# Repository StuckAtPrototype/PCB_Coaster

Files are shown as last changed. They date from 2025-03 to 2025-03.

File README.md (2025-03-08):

# PCB Coaster - StuckAtPrototype

## Youtube Video
A bit of a back-story of how this project came to be. 

My Kickstarter failed, so I open sourced it (https://youtu.be/eh7vAip87YQ)

Sub if you like what you see.

*Some pictures of the project*

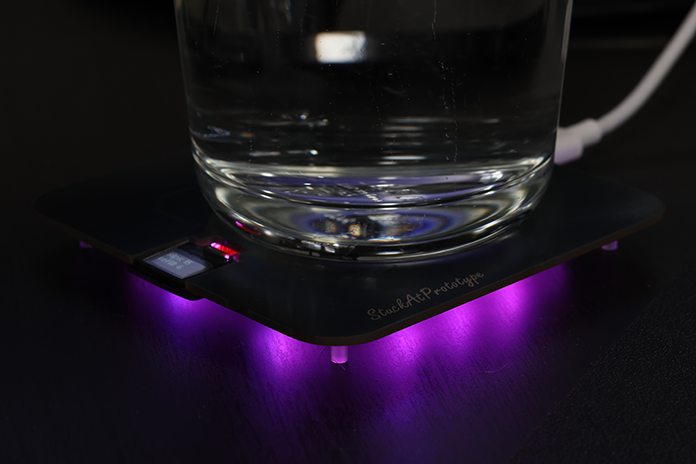
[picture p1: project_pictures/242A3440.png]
Picture of PCB car


## Project Structure
The project consists of
1. Firmware
2. Hardware
3. Mechanical

These are structured into their own files. I could have used submodules, but decided against it.  

### 1. Firmware
Code for the coaster. This lives on the ESP32

#### Requirements
- ESP32 IDF version 5.4
- Target set to ESP32-H2
- Install managed components  

##### Required Managed Components
1. lvgl 
2. espressif esp lvgl port

### 2. Hardware

#### Schematic
PDF schematic included for your viewing pleasure. File `PCB_Coaster_v0.2_Schematic.pdf`

#### PCBs
All the gerber files you'd need to send to a fab house. File `PCB coaster v0.2.zip`

#### BOM
Bill of materials file `coaster-BOM-v0.2.csv`

#### Kicad
All the files you'd need to expand and work on this further. If you'd like.

### 3. Mechanical

#### Diffuser
`PCB Coaster diffuser.step`
You can print this part with clear ABS fillament for best results. 

#### Screen Holder
`PCB Coaster screen holder.step`
I printed this part with an SLA printer, it can probably do ok with a filament printer too 

#### Spacers
`PCB Coaster spacer.step`
These print best on SLA. Filament printer will not achieve flat tops, though it might work. Best printed with SLA.  

#### Screen protector
I used a Cricut machine and a thin accental plastic to cut out the screen protector. Ideally, this would be made of tempered glass. (maybe one day)

## If you take it further
Let me know if you ever make one of these, I'd love to see it. Seriously, that'd be exciting and inspiring to keep making my projects open source!

## And if you got this far...
Consider signing up for my mailing list. As I run into problems when making these projects, I fire off an email with a small write up explaing the problem and the solution I found. Here is the link https://landing.stuckatprototype.com/exclusive

Stay fun, StuckAtPrototype

---
## License
### Apache 2.0 -- i.e. use as you'd like
http://www.apache.org/licenses/LICENSE-2.0

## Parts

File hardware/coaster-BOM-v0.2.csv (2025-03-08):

Id | Designator | Footprint | Quantity | Designation | Supplier and ref |  | PnP
1 | R17 | R_0603_1608Metric | 1 | 100k |  |  | y
2 | R5,R4 | R_0603_1608Metric | 2 | 5k1 |  |  | y
3 | U3 | AP2204 | 1 | AP2205 | AP2205-33W5-7 | 3v3
4 | U1 | AP2204 | 1 | AP2205 | AP2205-50W5-7 | 5v |  | bought
5 | C18,C4,C28,C10,C11,C17,C5,C3,C23,C6,C24,C8,C13,C7,C9,C21 | C_0603_1608Metric | 16 | 0.1uF |  |  | y
6 | LED9,LED6,LED1,LED8,LED7,LED3,LED11,LED4,LED5,LED10,LED2 | IN-PI15_INL | 11 | IN-PI15TAT5R5G5B | IN-PI15TAT5R5G5B |  |  | bought
7 | R11,R9,R10,R12 | R_0603_1608Metric | 4 | 1.43K |  |  | y
8 | R3 | R_0603_1608Metric | 1 | 470 |  |  |  | bought
9 | C25,C19,C1 | C_0603_1608Metric | 3 | 2.2uF |  |  |  | bought
10 | R14,R13,R1,R2,R16 | R_0603_1608Metric | 5 | 10k |  |  | y
11 | P1 | GCT_USB4105-GF-A | 1 | USB_C_Plug_USB2.0 | USB4125-GF-A |  |  | bought
12 | C12,C27 | C_0603_1608Metric | 2 | 4.7uF |  |  | y
13 | C26,C2 | C_0603_1608Metric | 2 | 10uF |  |  | y
14 | D1 | D_SOD-523 | 1 | TPD1E10B06DPYR | UCLAMP0501H.TCT | *Changed |  | bought
15 | Q1 | SOT-23 | 1 | BSS138 | BSS138 |  |  | bought
16 | R8,R18,R7 | R_0603_1608Metric | 3 | 10K |  |  | y
17 | P3,P2,P5,P4 | SEN0297 | 4 | SEN0297 | SEN0297
18 | U2 | MODULE_ESP32-H2-MINI-1-H2 | 1 | ESP32-H2-MINI-1 | ESP32-H2-MINI-1
19 | C14,C15,C20,C22 | C_0603_1608Metric | 2 | 1uF |  |  | y
20 | C16 | C_0603_1608Metric | 1 | 47uF
21 | R6 | R_0603_1608Metric | 1 | 1M |  |  | y
22 | S3 | TL1016AAF220QG | 1 | TL1016AAF220QG | TL1016AAF220QG |  |  | bought

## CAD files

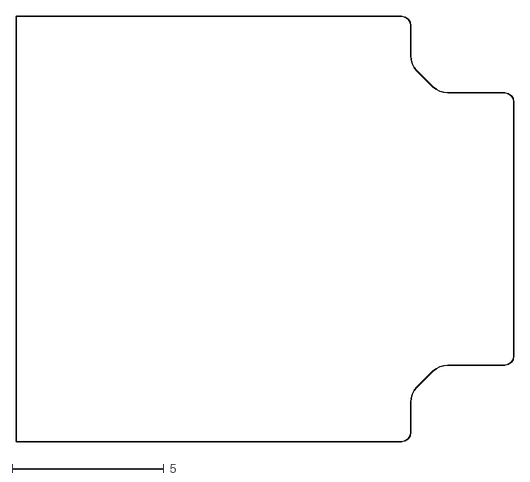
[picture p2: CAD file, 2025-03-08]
mechanical/screen-cover.dxf
16.4 x 14.0

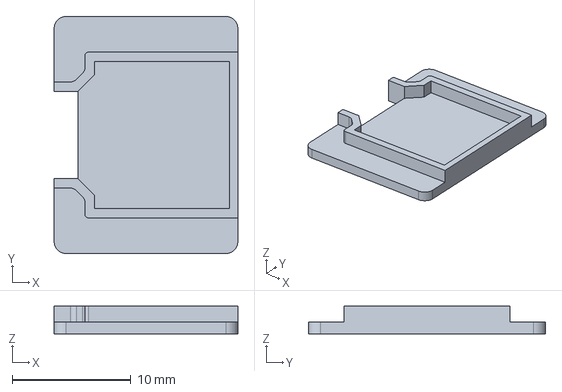
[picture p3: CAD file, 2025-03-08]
mechanical/PCB Coaster screen holder.step
15.5 x 20.0 x 2.36 mm

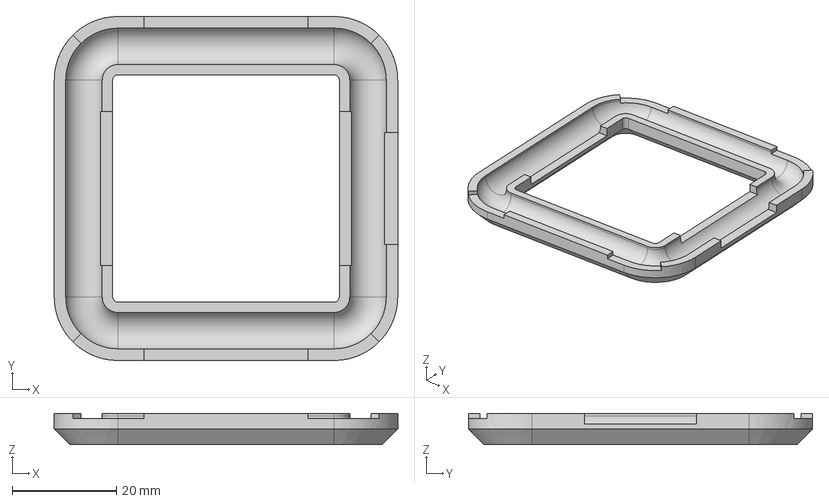
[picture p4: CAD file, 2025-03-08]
mechanical/PCB Coaster diffuser.step
65.8 x 65.9 x 6.00 mm

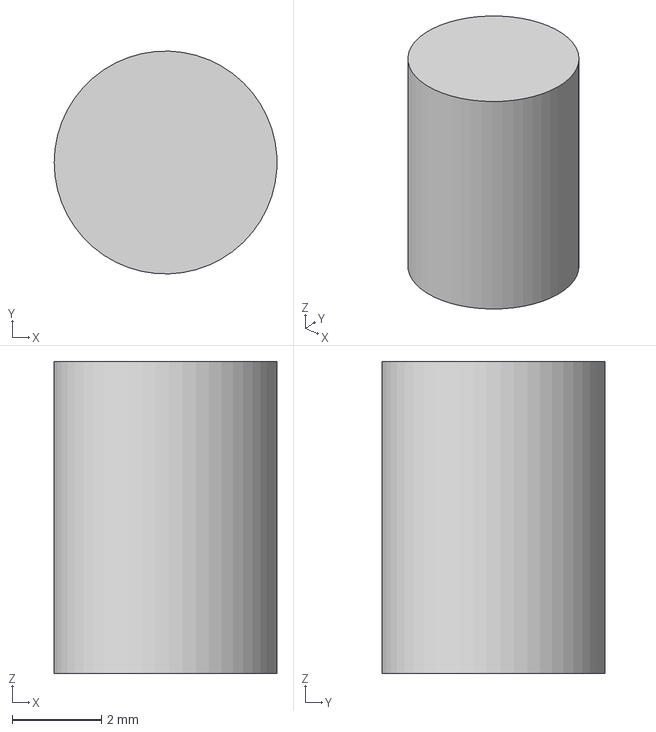
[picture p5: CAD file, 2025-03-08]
mechanical/PCB Coaster spacer.step
5.00 x 5.00 x 7.00 mm

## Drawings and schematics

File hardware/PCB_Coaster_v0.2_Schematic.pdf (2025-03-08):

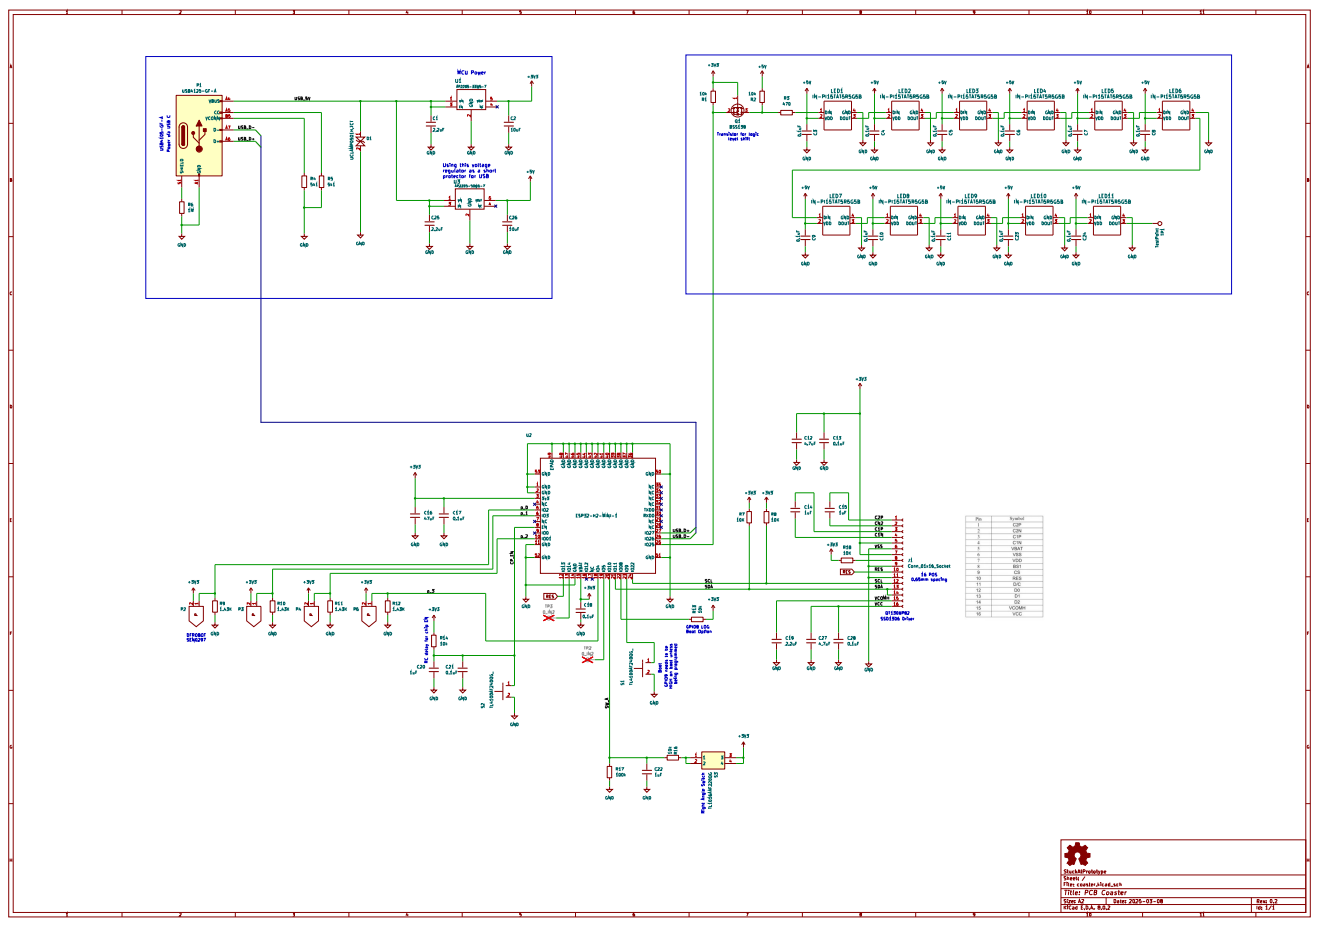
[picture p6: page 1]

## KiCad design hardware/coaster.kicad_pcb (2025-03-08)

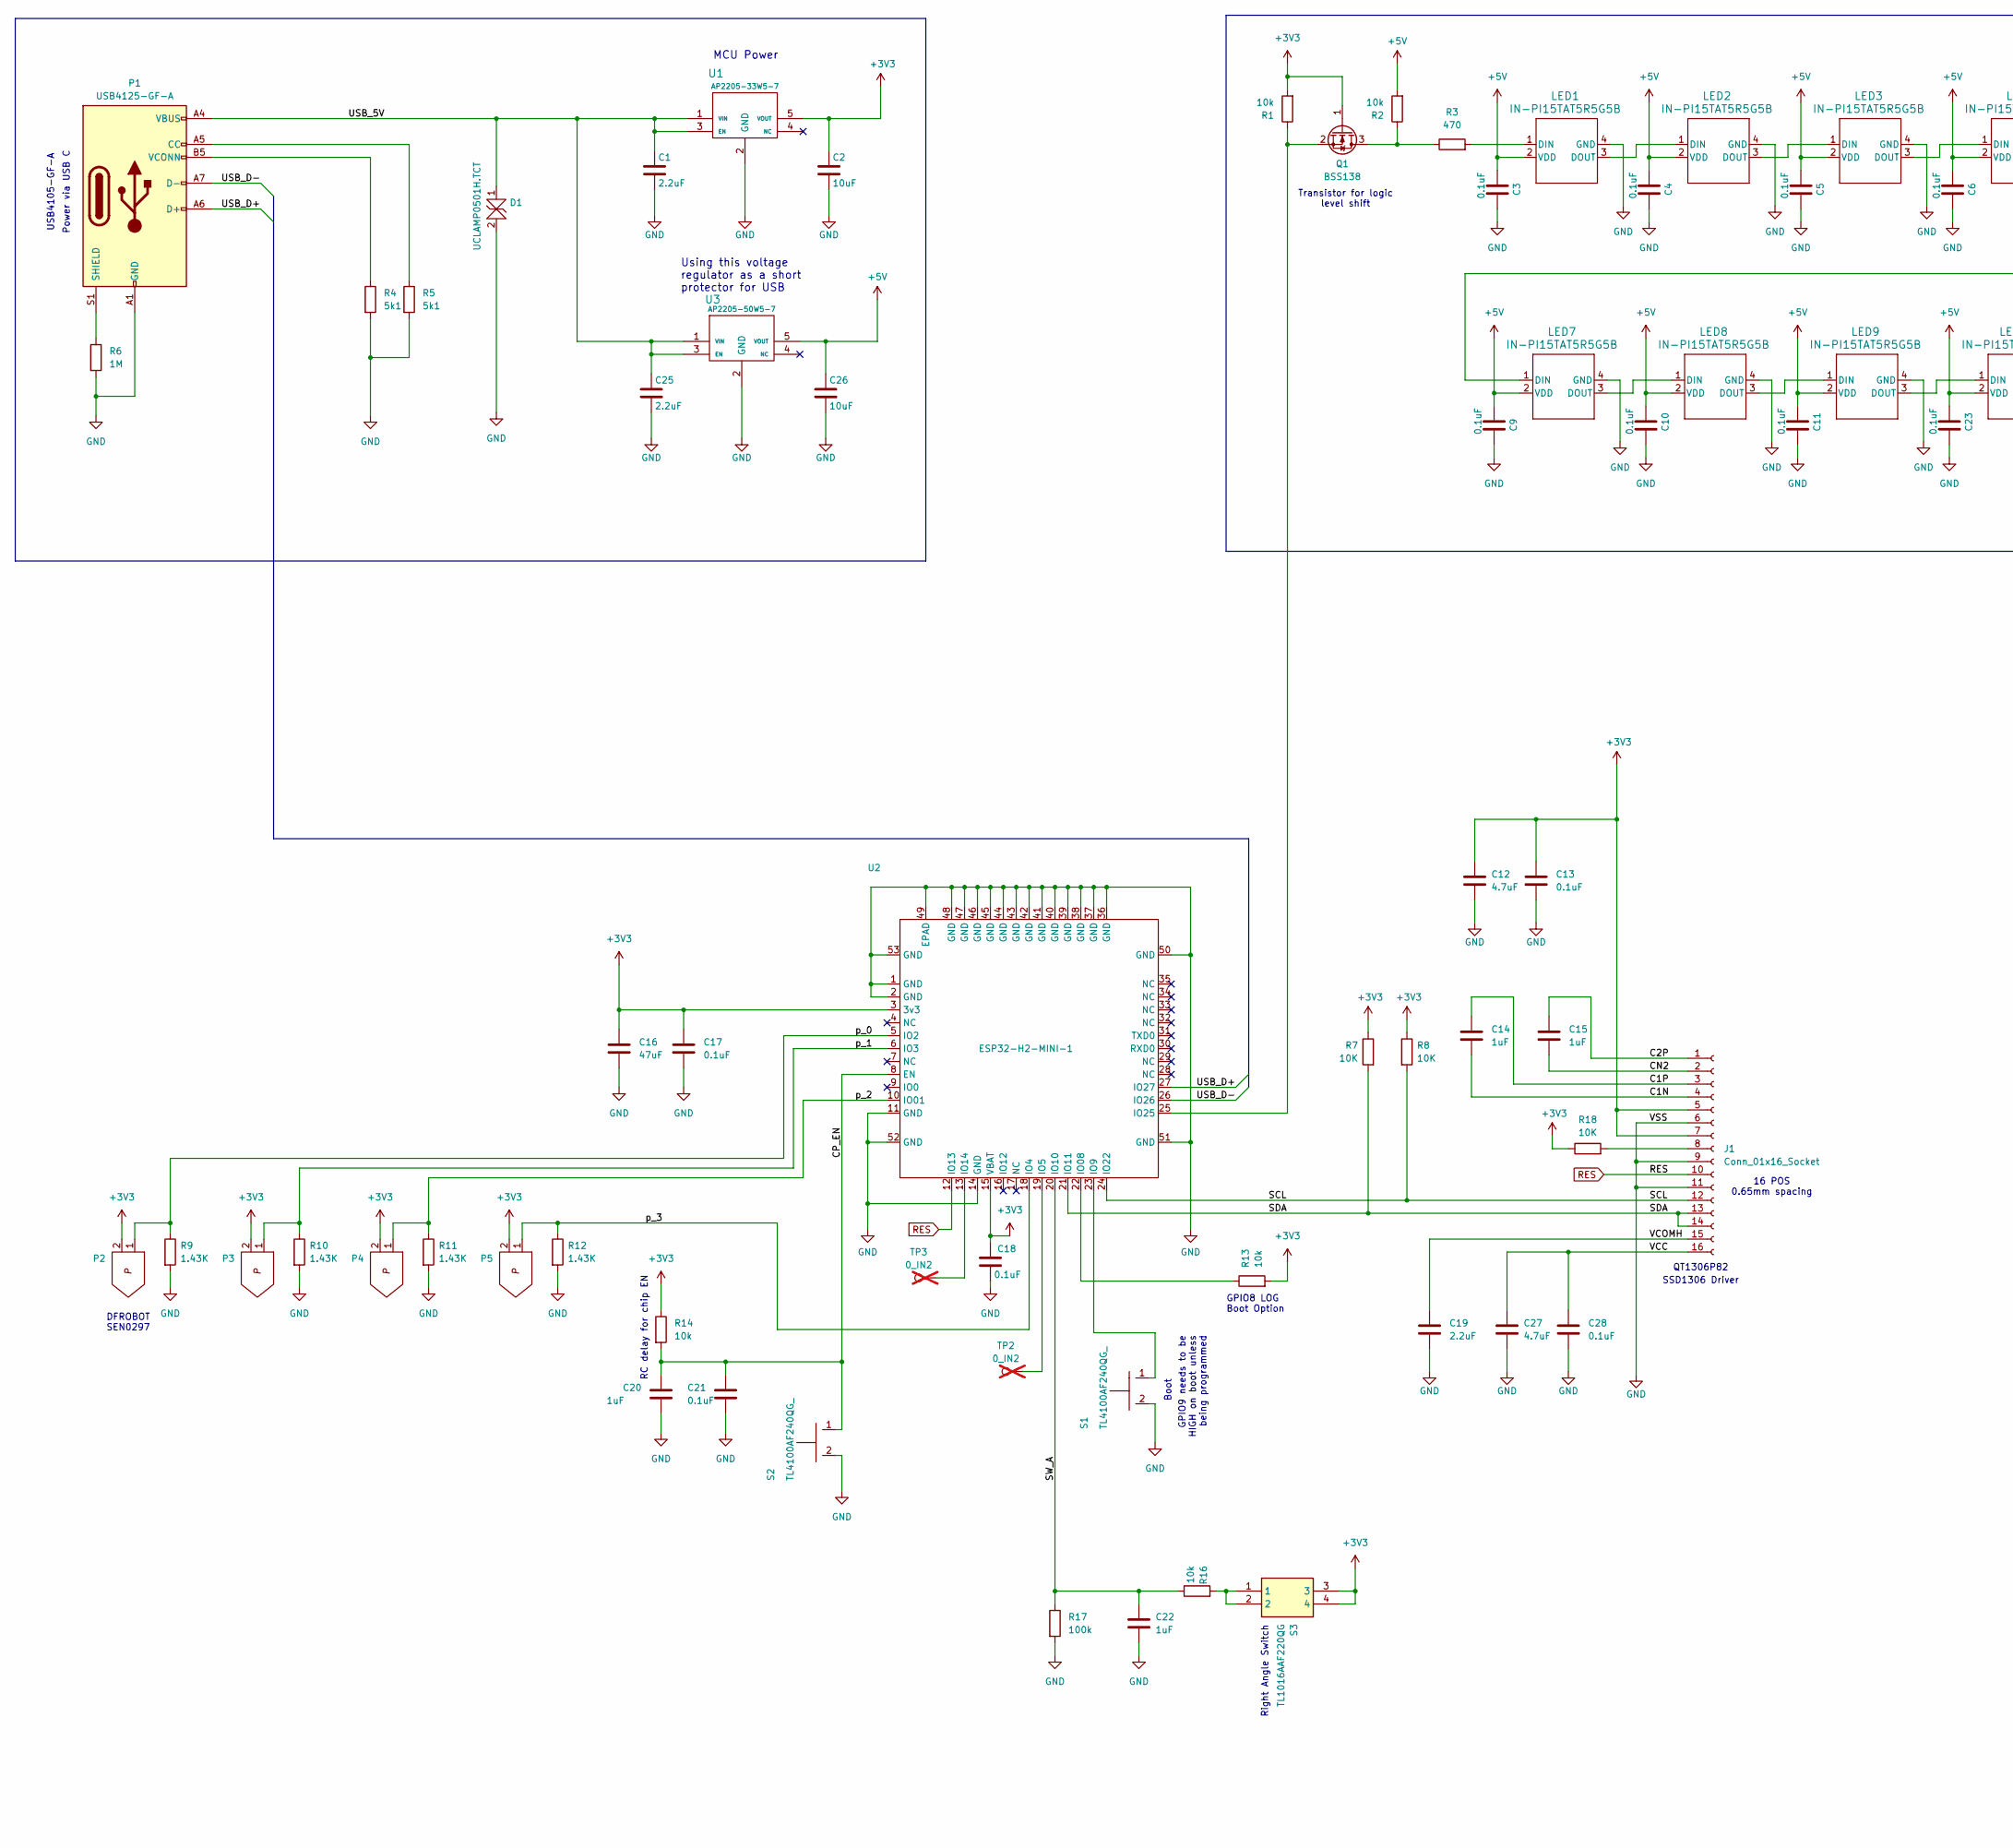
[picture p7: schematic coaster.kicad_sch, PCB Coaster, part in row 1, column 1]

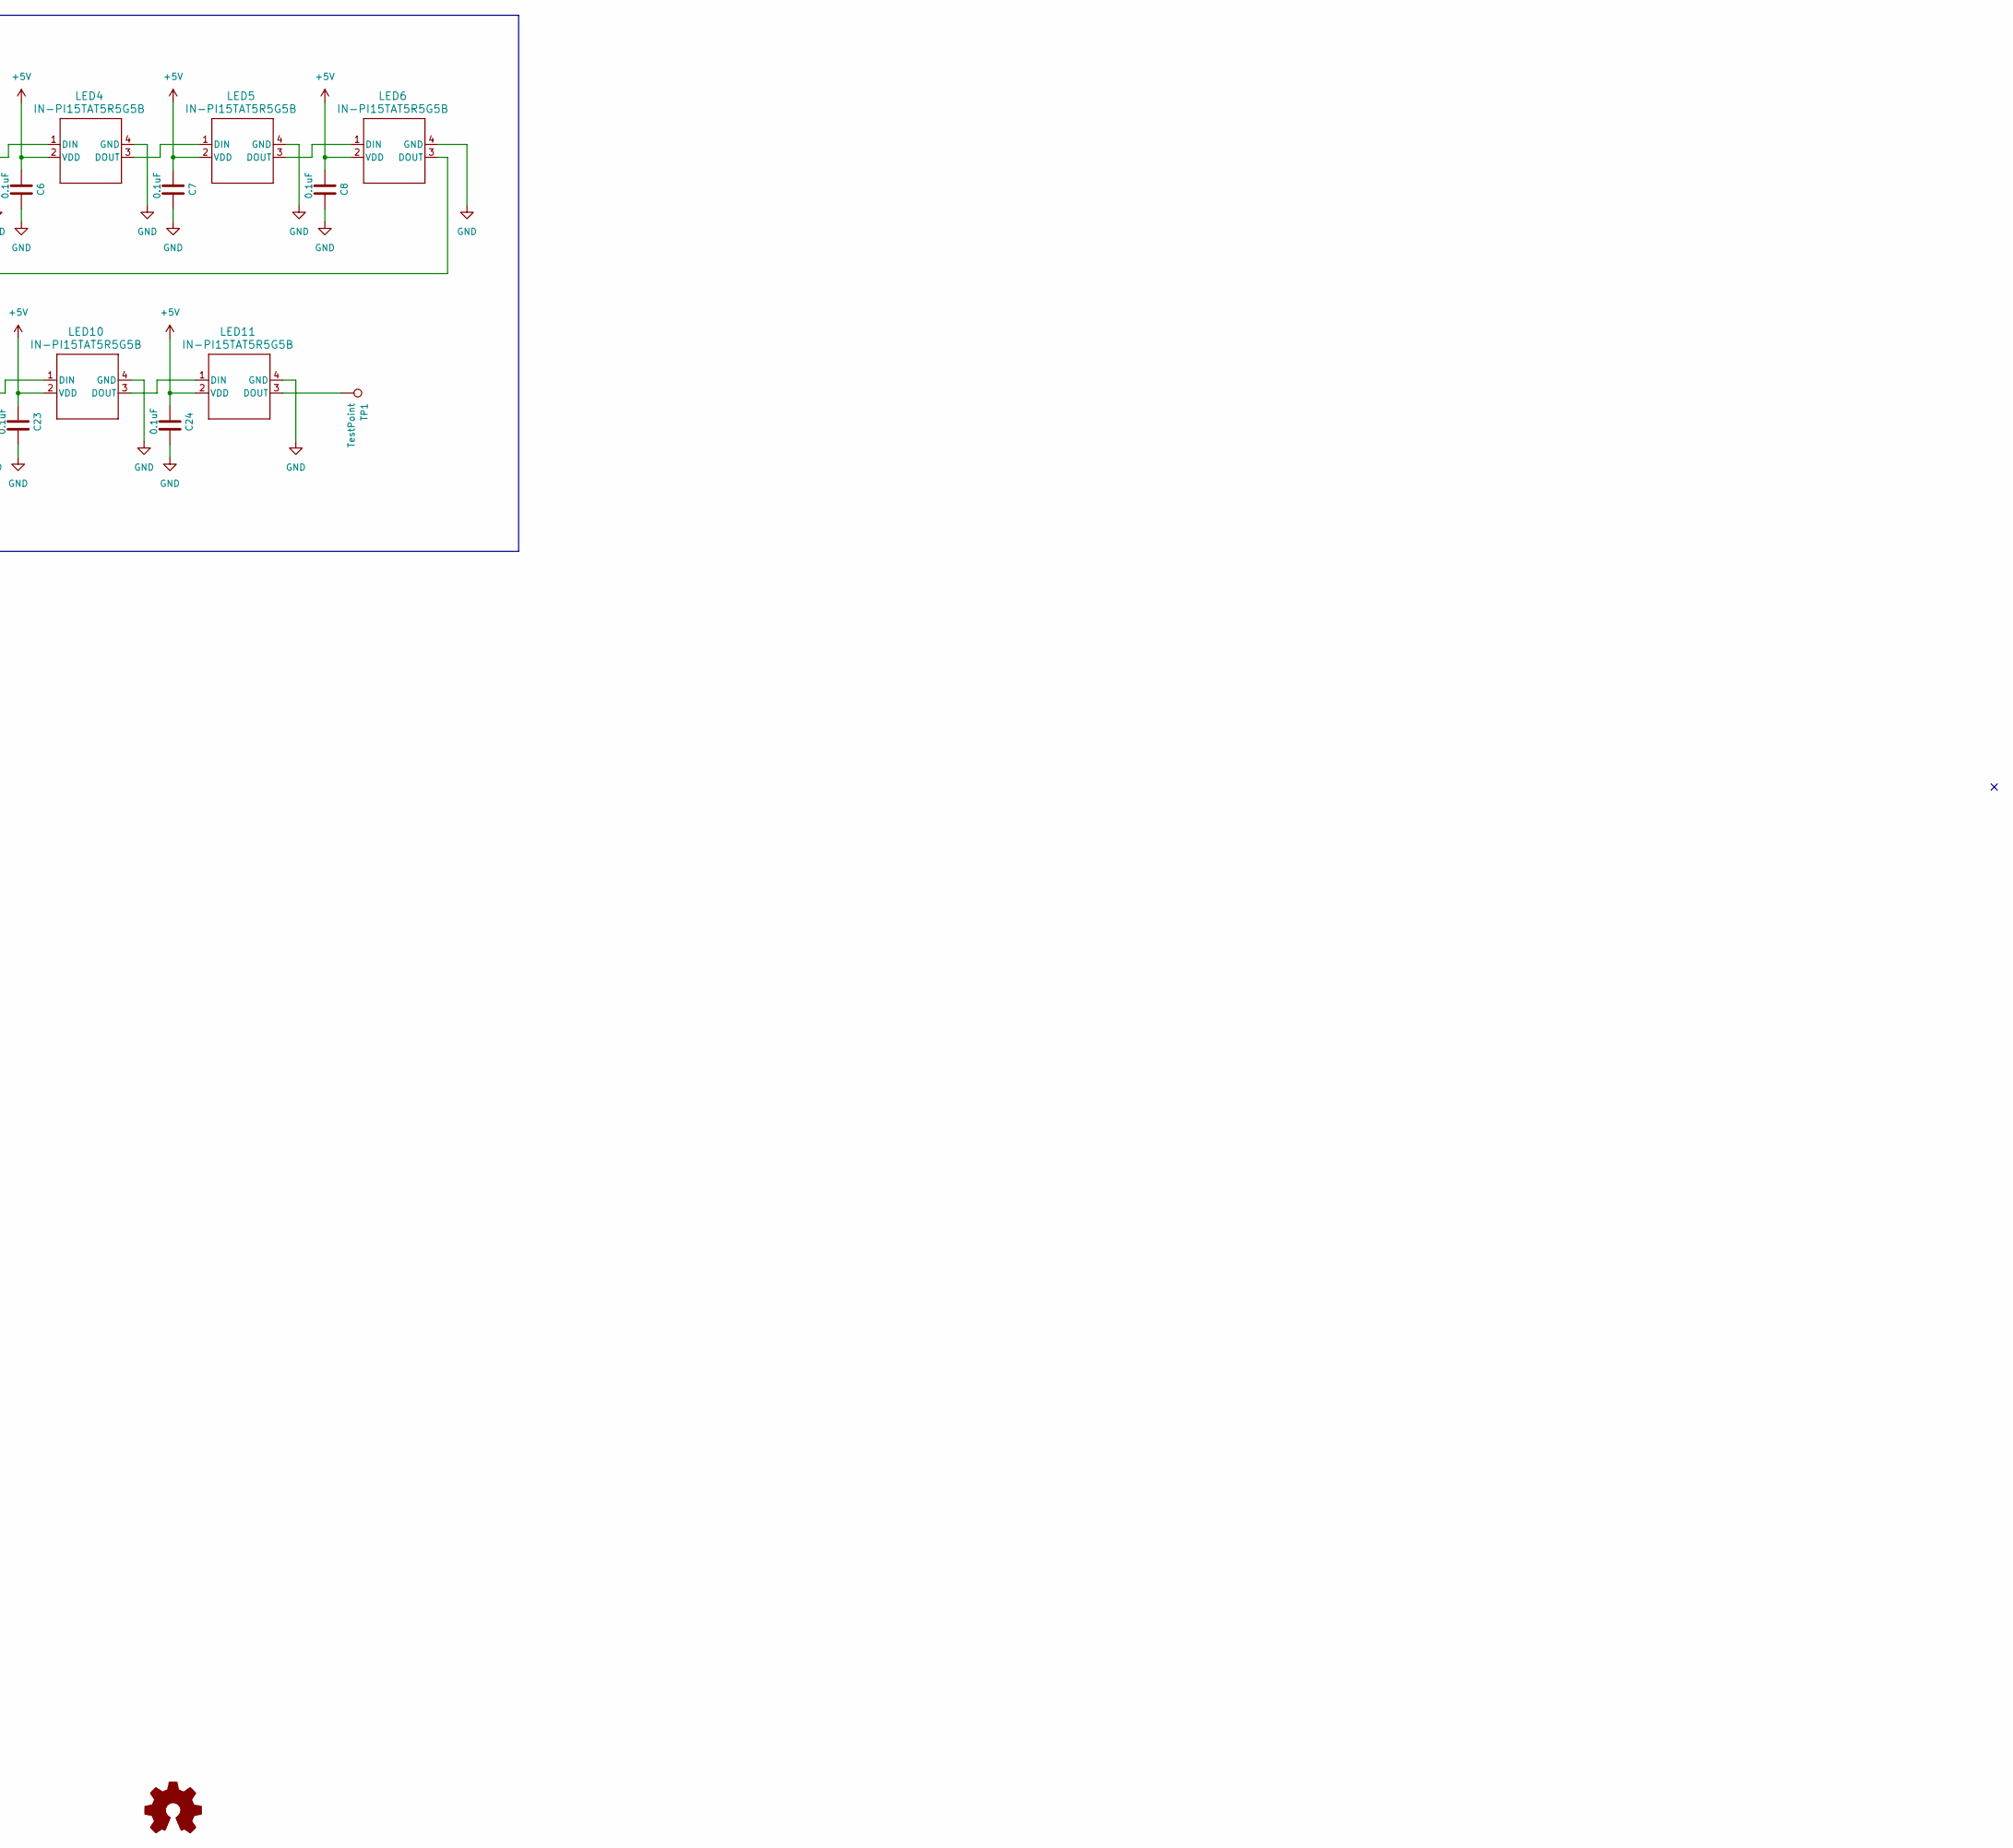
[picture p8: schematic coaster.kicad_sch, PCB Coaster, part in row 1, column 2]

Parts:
C1, C19, C25: 2.2uF; C_0603_1608Metric
C2, C26: 10uF; C_0603_1608Metric
C3, C4, C5, C6, C7, C8, C9, C10, C11, C13, C17, C18, C21, C23, C24, C28: 0.1uF; C_0603_1608Metric
C12, C27: 4.7uF; C_0603_1608Metric
C14, C15, C20, C22: 1uF; C_0603_1608Metric
C16: 47uF; C_0603_1608Metric
D1: UCLAMP0501H.TCT; D_SOD-523
J1: Conn_01x16_Socket; SMT_FFC_16X0.65
LED1, LED2, LED3, LED4, LED5, LED6, LED7, LED8, LED9, LED10, LED11: IN-PI15TAT5R5G5B; IN-PI15_INL
P1: USB4125-GF-A; GCT_USB4105-GF-A
P2, P3, P4, P5: SEN0297
Q1: BSS138; SOT-23
R1, R2, R13, R14, R16: 10k; R_0603_1608Metric
R3: 470; R_0603_1608Metric
R4, R5: 5k1; R_0603_1608Metric
R6: 1M; R_0603_1608Metric
R7, R8, R18: 10K; R_0603_1608Metric
R9, R10, R11, R12: 1.43K; R_0603_1608Metric
R17: 100k; R_0603_1608Metric
S1, S2: TL4100AF240QG_; SW_PTS810_SJM_250_SMTR_LFS
S3: TL1016AAF220QG; Mouser Part Number 612-TL1016AAF220QG
TP1: TestPoint; TestPoint_Pad_2.0x2.0mm
TP2, TP3: 0_IN2; TestPoint_Pad_1.0x1.0mm; not fitted
U1: AP2205-33W5-7; AP2204
U2: ESP32-H2-MINI-1; MODULE_ESP32-H2-MINI-1-H2
U3: AP2205-50W5-7; AP2204

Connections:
+3V3: C2.1, C12.1, C13.1, C16.1, C17.1, C18.1, J1.5, J1.7, P2.2, P3.2, P4.2, P5.2, Q1.1 (G), R1.2, R7.1, R8.1, R13.2, R14.1, R18.1, S3.3, S3.4, U1.5 (VOUT), U2.3 (3v3), U2.15 (VBAT)
+5V: C3.1, C4.1, C5.1, C6.1, C7.1, C8.1, C9.1, C10.1, C11.1, C23.1, C24.1, C26.1, LED1.2 (VDD), LED2.2 (VDD), LED3.2 (VDD), LED4.2 (VDD), LED5.2 (VDD), LED6.2 (VDD), LED7.2 (VDD), LED8.2 (VDD), LED9.2 (VDD), LED10.2 (VDD), LED11.2 (VDD), R2.2, U3.5 (VOUT)
/C1N: C14.2, J1.4
/C1P: C14.1, J1.3
/C2P: C15.1, J1.1
/CN2: C15.2, J1.2
/CP_EN: C20.1, C21.1, R14.2, S2.1, U2.8 (EN)
/SCL: J1.12, R8.2, U2.24 (IO22)
/SDA: J1.13, J1.14, R7.2, U2.21 (IO11)
/SW_A: C22.1, R16.1, R17.1, U2.20 (IO10)
/USB_5V: C1.1, C25.1, D1.1, P1.A4 (VBUS), P1.A9 (VBUS), P1.B4 (VBUS), P1.B9 (VBUS), U1.1 (VIN), U1.3 (EN), U3.1 (VIN), U3.3 (EN)
/USB_D+: P1.A6 (D+), U2.27 (IO27)
/USB_D-: P1.A7 (D-), U2.26 (IO26)
/VCC: C27.1, C28.1, J1.16
/VCOMH: C19.1, J1.15
/p_0: P2.1, R9.1, U2.5 (IO2)
/p_1: P3.1, R10.1, U2.6 (IO3)
/p_2: P4.1, R11.1, U2.10 (IO01)
/p_3: P5.1, R12.1, U2.18 (IO4)
GND: C1.2, C2.2, C3.2, C4.2, C5.2, C6.2, C7.2, C8.2, C9.2, C10.2, C11.2, C12.2, C13.2, C16.2, C17.2, C18.2, C19.2, C20.2, C21.2, C22.2, C23.2, C24.2, C25.2, C26.2, C27.2, C28.2, D1.2, J1.6, J1.9, J1.11, LED1.4 (GND), LED2.4 (GND), LED3.4 (GND), LED4.4 (GND), LED5.4 (GND), LED6.4 (GND), LED7.4 (GND), LED8.4 (GND), LED9.4 (GND), LED10.4 (GND), LED11.4 (GND), P1.A1 (GND), P1.A12 (GND), P1.B1 (GND), P1.B12 (GND), R4.2, R5.2, R6.2, R9.2, R10.2, R11.2, R12.2, R17.2, S1.2, S2.2, U1.2 (GND), U2.1 (GND), U2.2 (GND), U2.11 (GND), U2.14 (GND), U2.36 (GND), U2.37 (GND), U2.38 (GND), U2.39 (GND), U2.40 (GND), U2.41 (GND), U2.42 (GND), U2.43 (GND), U2.44 (GND), U2.45 (GND), U2.46 (GND), U2.47 (GND), U2.48 (GND), U2.49 (EPAD), U2.50 (GND), U2.51 (GND), U2.52 (GND), U2.53 (GND), U3.2 (GND)
unnamed: J1.8, R18.2
unnamed: LED1.1 (DIN), R3.2
unnamed: LED1.3 (DOUT), LED2.1 (DIN)
unnamed: LED2.3 (DOUT), LED3.1 (DIN)
unnamed: LED3.3 (DOUT), LED4.1 (DIN)
unnamed: LED4.3 (DOUT), LED5.1 (DIN)
unnamed: LED5.3 (DOUT), LED6.1 (DIN)
unnamed: LED6.3 (DOUT), LED7.1 (DIN)
unnamed: LED7.3 (DOUT), LED8.1 (DIN)
unnamed: LED8.3 (DOUT), LED9.1 (DIN)
unnamed: LED9.3 (DOUT), LED10.1 (DIN)
unnamed: LED10.3 (DOUT), LED11.1 (DIN)
unnamed: LED11.3 (DOUT), TP1.1
unnamed: P1.A5 (CC), R5.1
unnamed: P1.S1 (SHIELD), R6.1
unnamed: P1.B5 (VCONN), R4.1
unnamed: Q1.3 (D), R2.1, R3.1
unnamed: Q1.2 (S), R1.1, U2.25 (IO25)
unnamed: R16.2, S3.1, S3.2
unnamed: TP2.1, U2.19 (IO5)
unnamed: R13.1, U2.22 (IO08)
unnamed: S1.1, U2.23 (IO9)
unnamed: TP3.1, U2.13 (IO14)
RES: J1.10, U2.12 (IO13)

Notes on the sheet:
MCU Power
16 POS 0.65mm spacing
Power via USB C
RC delay for chip EN
Using this voltage regulator as a short protector for USB
GPIO8 LOG Boot Option
Boot
Right Angle Switch
GPIO9 needs to be HIGH on boot unless being programmed
USB4105-GF-A
Transistor for logic level shift
SSD1306 Driver
DFROBOT SEN0297
QT1306P82

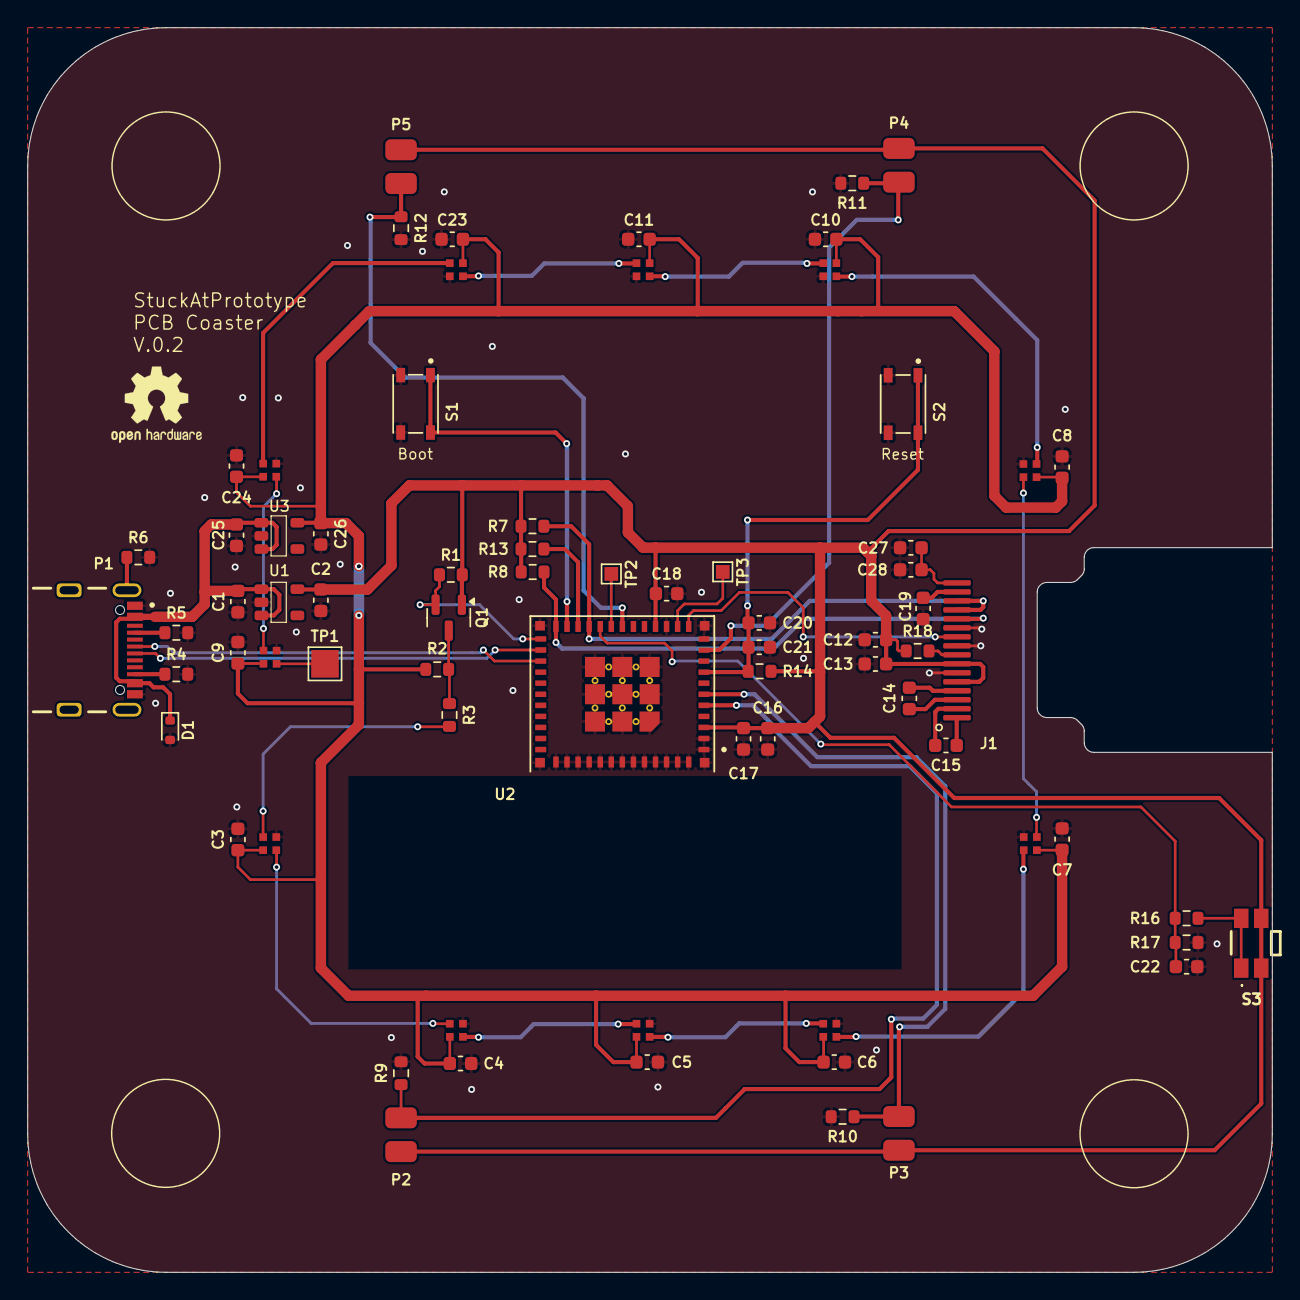
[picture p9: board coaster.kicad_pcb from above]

Board: 2 copper layers, 90.0 x 90.0 mm, 73 parts (0 on the bottom side), 44 nets.

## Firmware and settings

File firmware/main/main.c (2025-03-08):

#include <stdio.h>
#include <inttypes.h>
#include "sdkconfig.h"
#include "freertos/FreeRTOS.h"
#include "freertos/task.h"
#include "esp_system.h"

#include "esp_log.h"
#include <math.h>

#include "ws2812_control.h"
#include "adc_readings.h"
#include "driver/temperature_sensor.h"

#include "screen.h"
#include "user_interface.h"

#include "weight_lookup.h"
#include "water_state.h"
#include "led_color_lib.h"

#include "button_handler.h"

static const char *TAG = "main";

temperature_sensor_handle_t temp_sensor = NULL;

struct led_state new_state1;

uint32_t last_active_screen = 0;


float get_average_weight_counts(void){
    float voltages[5];

    // Call the function to get voltages
    adc_readings_get_voltages(voltages);

    float avg = 0;
    for(int i = 0; i < 4; i++)
        avg+=voltages[i];
    avg = avg/4;

    return avg;
}

void read_and_print_voltages(void) {

    // add a weight reading to our
    add_weight_reading(lookup_and_extrapolate(get_average_weight_counts()));

    // esp32 internal temperature measurement
    float tsens_value;
    ESP_ERROR_CHECK(temperature_sensor_get_celsius(temp_sensor, &tsens_value));
    add_temperature_reading(tsens_value);

    // run cup logic
    process_cup();

    // screen text buffer
    char screen_text[32];

    // update screen 0 vars
    sprintf(screen_text, "sips: %i", water_state.sip_count);
    ui_set_scr_0_label_0_text(screen_text);

    sprintf(screen_text, "refill: %i", water_state.refill_count);
    ui_set_scr_0_label_1_text(screen_text);

    // update screen 1 vars
    // calculate minites remaining (rounded up)
    int minutes_remaining = REMINDER_INTERVAL_MINUTES - ceil((water_state.time_elapsed_since_last_event / 60000000.0)) + 1;
    int percentage_remaining = ceil(minutes_remaining / ((float)REMINDER_INTERVAL_MINUTES + 1) * 100.0);

    // issue a warning symbol if its been -20 minutes -- a bit of an easter egg :)
    if(minutes_remaining < -20){
        sprintf(screen_text, "%s", LV_SYMBOL_WARNING);
    } else {
        sprintf(screen_text, "%i", minutes_remaining);
    }
    ui_set_scr_1_label_0_text(screen_text);
    ui_set_scr_1_bar_0_value(percentage_remaining);

    sprintf(screen_text, "sips: %i", water_state.sip_count);
    ui_set_scr_1_label_1_text(screen_text);

    uint32_t color;
    float temp = temperature_average();
    if(water_state.drink_reminder == 1){
        // pulse light
        color = get_pulsing_color(0, 255, 0); // green
    } else {
        if(temp > 0){
            color = get_color_between_blue_red(temp);
        } else {
            color = get_next_color_full_spectrum();
        }
    }

    if(water_state.cup_state == CUP_NOT_PRESENT){
        // we need to be able to clear this screen with a button press or time
        if(water_state.time_elapsed_since_last_event < 2500000){  // 2500000 == 2.5 seconds
            if(ui_get_active_screen_num() != UI_SCREEN_SPLASH){
                ui_set_active_screen(UI_SCREEN_SPLASH);
            }
        } else {
            ui_set_active_screen(last_active_screen);
        }

    } else {
       if(ui_get_active_screen_num() == UI_SCREEN_SPLASH){
            ui_set_active_screen(last_active_screen);
        }
    }


    // write the leds
    for(int i = 0; i < 11; i++)
        new_state1.leds[i] = color;
    ws2812_write_leds(new_state1);

}

/* Drivers
 * (x) WS2812
 * (X) Display
 * (X) ADC
 */

/* Logical Drivers
 * - light up LEDS
 * - drive display
 * - measure resistance
 * -- temperature
 * -- weight
 * - calculate liquid consumption
 * - read button (interrupt)
 */
void app_main(void)
{
    ESP_LOGI(TAG, "starting up");

    // init the screen and lvgl
    screen_init();

    // initiate the active screen variable
    last_active_screen = ui_get_active_screen_num();

    // initialize ADC
    adc_readings_init();

    // init led driver
    ws2812_control_init();
    ESP_LOGI(TAG, "ws driver initialized!!");

    // temperature sensor
    ESP_LOGI(TAG, "Install temperature sensor, expected temp ranger range: 10~50 ℃");
    temperature_sensor_config_t temp_sensor_config = TEMPERATURE_SENSOR_CONFIG_DEFAULT(10, 50);
    ESP_ERROR_CHECK(temperature_sensor_install(&temp_sensor_config, &temp_sensor));

    ESP_LOGI(TAG, "Enable temperature sensor");
    ESP_ERROR_CHECK(temperature_sensor_enable(temp_sensor));

    // enable button
    button_handler_init();

    while (1) {

        read_and_print_voltages();

        // read in the button buffer
        QueueHandle_t button_queue = button_get_queue_handle();
        button_event_t event_data;
        if(xQueueReceive(button_queue, &event_data, 0)){
            if(event_data == BUTTON_SHORT_PRESS){
                // switch the active user interface to the next one
                last_active_screen = ui_advance_screen();
            } else if (event_data == BUTTON_LONG_PRESS){
                water_reset_stats();
            }
        }
        vTaskDelay(10 / portTICK_PERIOD_MS);  // Delay
    }
}

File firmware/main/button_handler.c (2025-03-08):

#include "button_handler.h"
#include "freertos/FreeRTOS.h"
#include "freertos/task.h"
#include "freertos/queue.h"
#include "esp_timer.h"
#include "esp_log.h"

static const char *TAG = "BUTTON_HANDLER";

QueueHandle_t gpio_evt_queue = NULL;
static TaskHandle_t button_task_handle = NULL;


typedef struct {
    uint64_t last_event_time;
    button_state_t last_button_state;
    button_event_t button_event;
    uint8_t button_event_started;
} ButtonStateMachine;

// button state machine
ButtonStateMachine button_sm = {
        .last_event_time = 0,
        .last_button_state = BUTTON_LOW,
        .button_event = BUTTON_NONE,
        .button_event_started = 0
};

QueueHandle_t button_get_queue_handle(void) {
    return gpio_evt_queue;
}

static void button_task(void* arg)
{
    button_event_t event;
    while(1) {
        // Check if it's a high or low
        if (gpio_get_level(BUTTON_PIN) == 1) {

            // check if we are currently in a event started mode and if the last button state was low
            if (button_sm.button_event_started == 0 && button_sm.last_button_state == BUTTON_LOW) {
                button_sm.last_event_time = esp_timer_get_time();
                button_sm.button_event_started = 1;
            } else if (button_sm.button_event_started == 1){
                // exit point for a long press
                uint64_t time_now = esp_timer_get_time();
                if(time_now - button_sm.last_event_time >= LONG_PRESS_TIME_MICROS){
                    event = BUTTON_LONG_PRESS;
                    ESP_LOGI(TAG, "Long press detected");

                    // clean up the state
                    button_sm.button_event_started = 0;

                    // send out the queue to the rest of the system
                    xQueueSend(gpio_evt_queue, &event, 0);
                }
            }
            // mark the state machine as button state high
            button_sm.last_button_state = BUTTON_HIGH;

        } else {
            // if the event is started and the last button state is high
            if(button_sm.button_event_started == 1 && button_sm.last_button_state == BUTTON_HIGH){

                // if time is greater than limit, post event as long press and stop and reset timer
                uint64_t time_now = esp_timer_get_time();
                if (time_now - button_sm.last_event_time <= LONG_PRESS_TIME_MICROS) {
                    ESP_LOGI(TAG, "Short press detected");
                    event = BUTTON_SHORT_PRESS;
                }
                // clean up the state
                button_sm.button_event_started = 0;

                // send out the queue to the rest of the system
                xQueueSend(gpio_evt_queue, &event, 0);
            }
            // mark the state machine as button state high
            button_sm.last_button_state = BUTTON_LOW;
        }
        vTaskDelay(pdMS_TO_TICKS(10));
    }
}

void button_handler_init(void)
{
    gpio_config_t io_conf = {
            .intr_type = GPIO_INTR_DISABLE,
            .mode = GPIO_MODE_INPUT,
            .pin_bit_mask = (1ULL << BUTTON_PIN),
            .pull_up_en = GPIO_PULLUP_DISABLE,
    };
    gpio_config(&io_conf);

    gpio_evt_queue = xQueueCreate(10, sizeof(uint32_t));
    xTaskCreate(button_task, "button_task", 2048, NULL, 10, &button_task_handle);

    ESP_LOGI(TAG, "Button handler initialized");
}
